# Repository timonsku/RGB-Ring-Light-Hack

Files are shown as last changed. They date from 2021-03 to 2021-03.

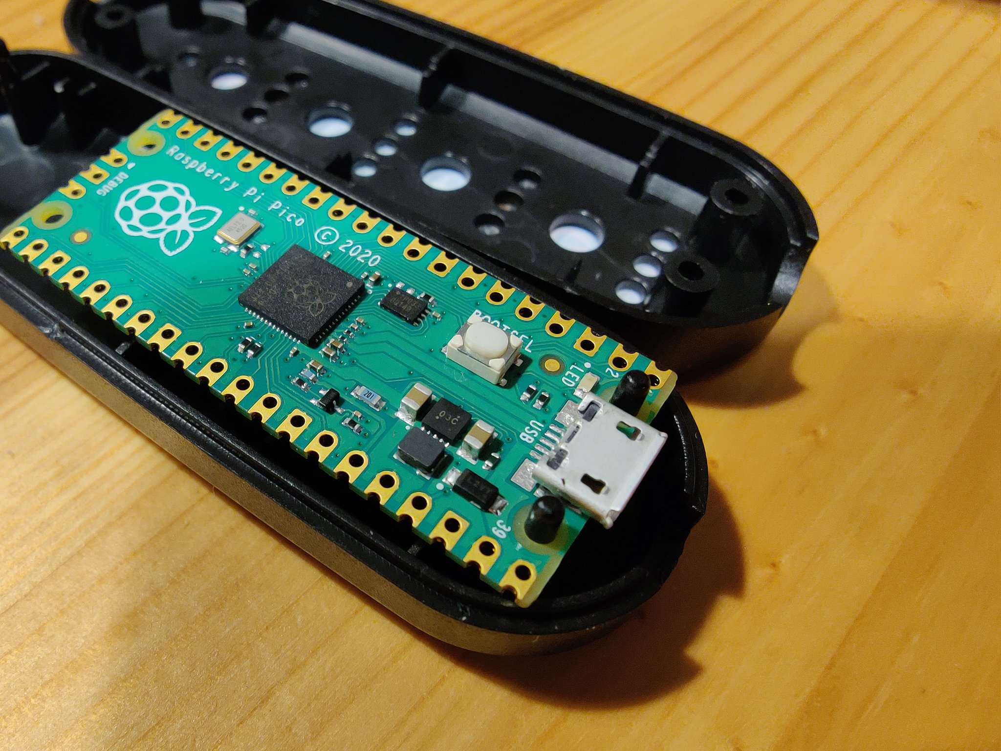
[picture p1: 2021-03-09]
Photos/pico-test-fit.jpg

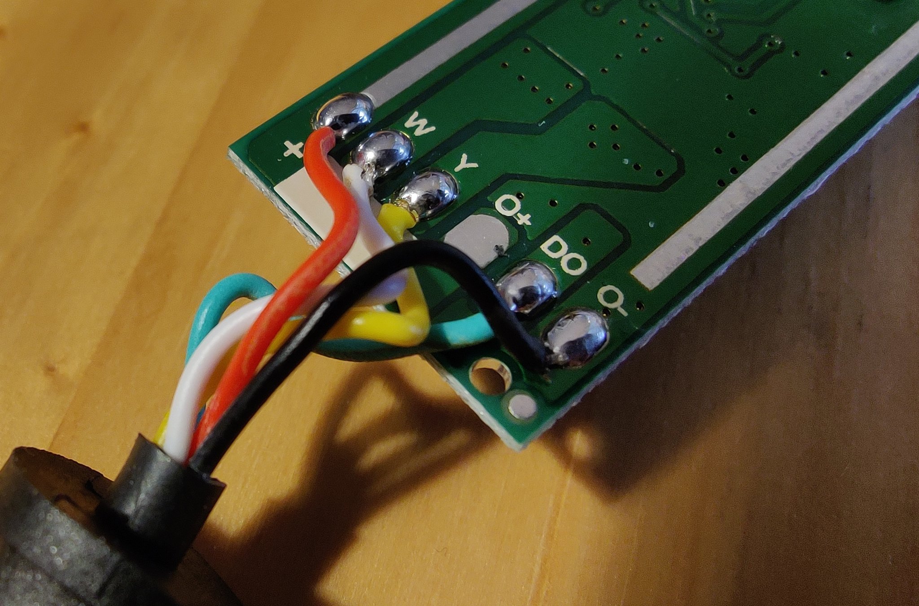
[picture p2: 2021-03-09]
Photos/pinout-original-controller.jpg

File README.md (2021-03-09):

# RGB-Ring-Light-Hack
Info and material to hack common RGB(W) ring lights with your own controller

The hack adds a Raspberry Pi Pico into the original case of the controller with some side cutter modifications and a backpack PCB that adds buttons and mosfets to control the cold and warm white LEDs.

This is based on a RGB ring light that you can buy from AliExpress, Ebay, Amazon etc.
The generic term is "10 Inch RGB Ring Light" or "10 Inch RGB Beauty Light"
The case hack that you can find in this repo is based on the model found from this vendor (affiliate link): https://s.click.aliexpress.com/e/_99rVuu

This is a high quality model of this ring light and I recommend getting that version. You might find cheaper models but they often use a different controller with a smaller case and generally a bit worse built quality, the PCB for the light seems to be generally the same though.

Demo Video

For reproducing you will need a Raspberry Pi Pico, order the PCB in `Case-Hack-PCB` and modify the case with a pair of flat side cutters according to the reference photos in `Case-Modification-Reference`. Beware of the cutouts for the buttons, you need to make them large enough so that the new buttons can fit, otherwise the case will not close well.

To open the case the first time, insert something flat/sharp between the edges of the two halfs and lever them apart, you may need to do that in multiple points before it comes apart. There is no snap fits, its just a pressure fit.

When soldering the PCB, take a look at `Case-Hack-PCB/solder-reference-headers.jpg` you need to trim the headers after soldering and add a header pointing in the opposite direction to the SWD pins for stabilization, those should be soldered first, otherwise its going to be difficult with the button pcb already in place.

I don't have the time to document this in a step by step manner. If anyone reproduces this and would like to do that, PR's are more than welcome.

Original Twitter thread with possibly some more details: https://twitter.com/timonsku/status/1357681117395103746

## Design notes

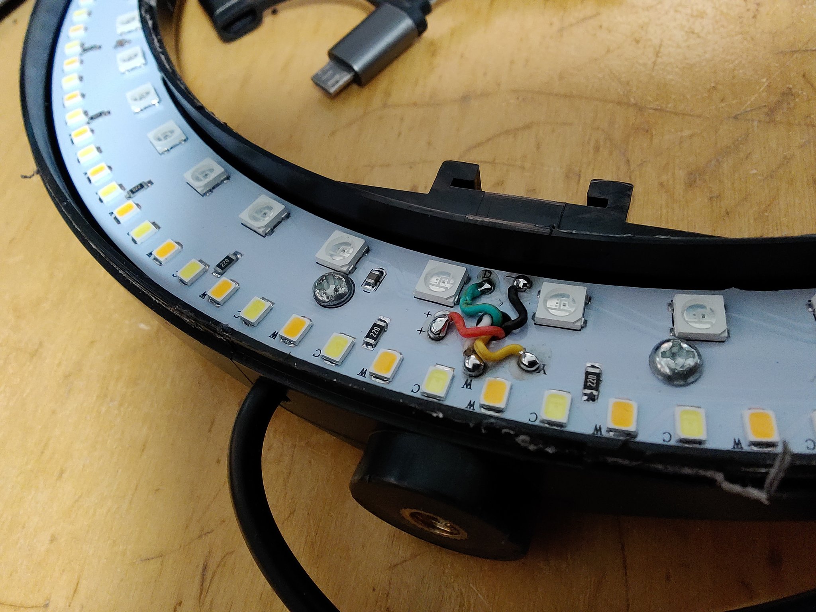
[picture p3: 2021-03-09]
Photos/inside-2.jpg

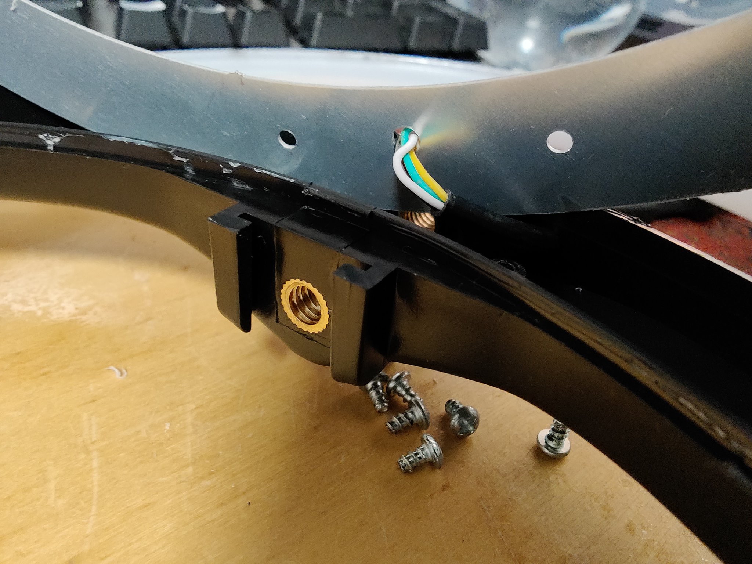
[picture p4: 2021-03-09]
Photos/inside-1.jpg

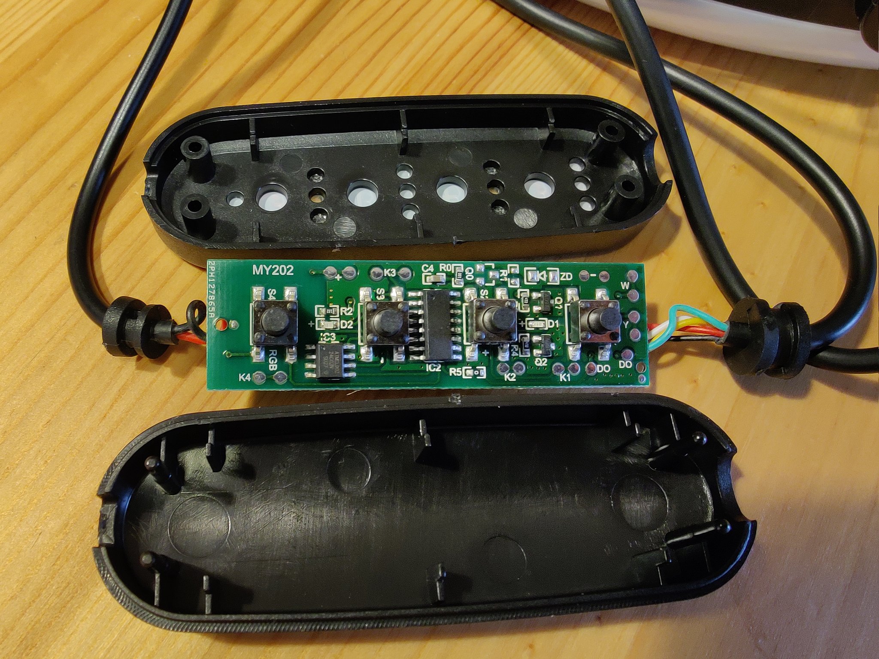
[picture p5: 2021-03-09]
Photos/original-controller.jpg

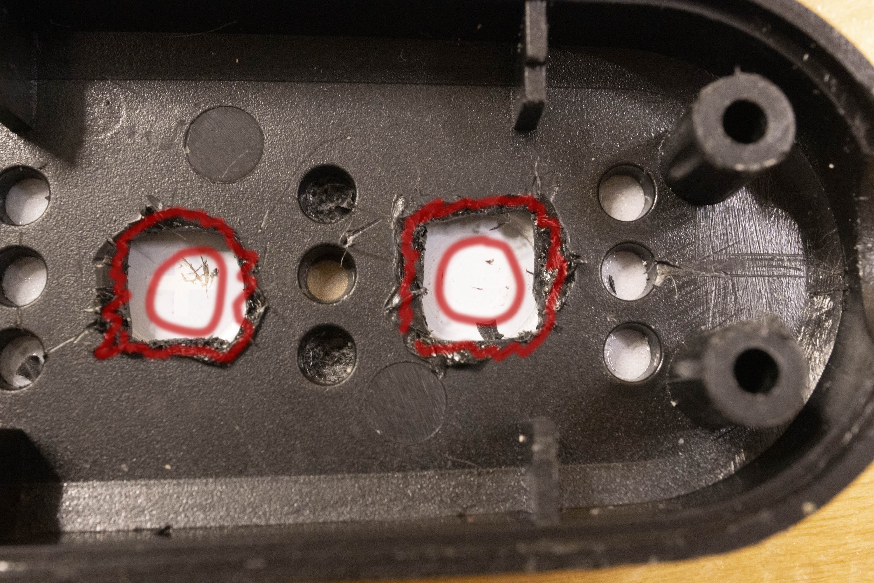
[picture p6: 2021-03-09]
Case-Modification-Reference/top-1.jpg

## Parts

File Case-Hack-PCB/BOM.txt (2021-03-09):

Buttons: K2-1109SP-B4SA-01 https://lcsc.com/product-detail/Tactile-Switches_Korean-Hroparts-Elec-K2-1109SP-B4SA-01_C92571.html

Mosfet: DMG3406L https://lcsc.com/product-detail/MOSFET_Diodes-Incorporated-DMG3406L-13_C481695.html

Generic 2.54mm Pin headers

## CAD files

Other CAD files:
Case-Hack-PCB/3D-CAD/Case-Top v10.f3z
Case-Hack-PCB/Case-Hack-PCB.f3z

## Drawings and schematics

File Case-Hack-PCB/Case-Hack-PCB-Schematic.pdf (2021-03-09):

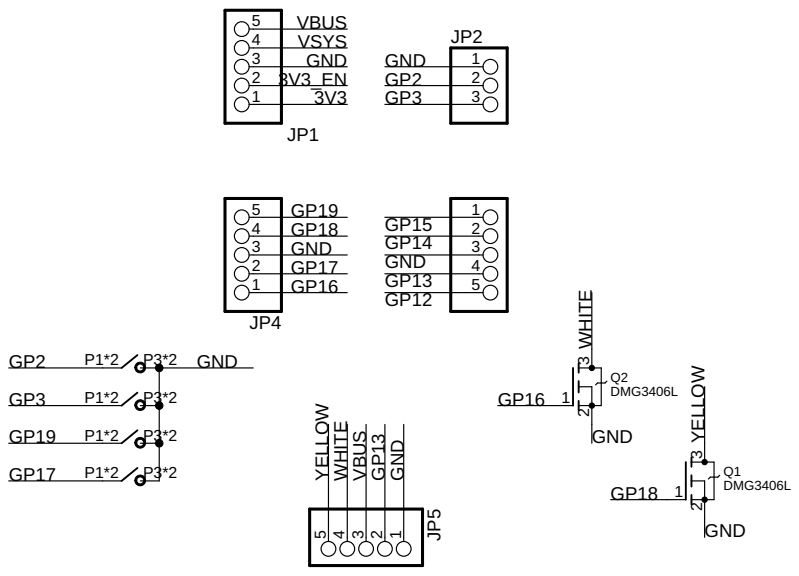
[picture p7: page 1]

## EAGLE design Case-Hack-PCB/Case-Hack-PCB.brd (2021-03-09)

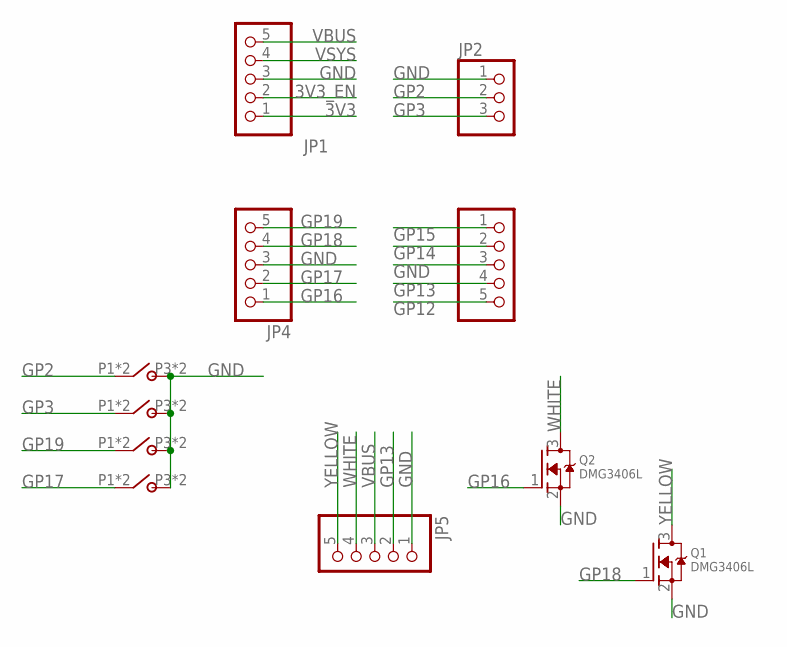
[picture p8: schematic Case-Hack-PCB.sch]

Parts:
JP1, JP3, JP4, JP5: HEADER-1X5ROUND; 1X05_ROUND
JP2: HEADER-1X3ROUND; 1X03_ROUND
Q1, Q2: DMG3406L; SOT23-WIDE
U$1, U$2, U$3, U$4: K2-1109SP-B4SA-01

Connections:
3V3: JP1.1
3V3_EN: JP1.2
GND: JP1.3, JP2.1, JP3.3, JP4.3, JP5.1, Q1.2 (S), Q2.2 (S), U$1.P3, U$1.P4, U$2.P3, U$2.P4, U$3.P3, U$3.P4, U$4.P3, U$4.P4
GP2: JP2.2, U$1.P1, U$1.P2
GP3: JP2.3, U$2.P1, U$2.P2
GP12: JP3.5
GP13: JP3.4, JP5.2
GP14: JP3.2
GP15: JP3.1
GP16: JP4.1, Q2.1 (G)
GP17: JP4.2, U$4.P1, U$4.P2
GP18: JP4.4, Q1.1 (G)
GP19: JP4.5, U$3.P1, U$3.P2
VBUS: JP1.5, JP5.3
VSYS: JP1.4
WHITE: JP5.4, Q2.3 (D)
YELLOW: JP5.5, Q1.3 (D)

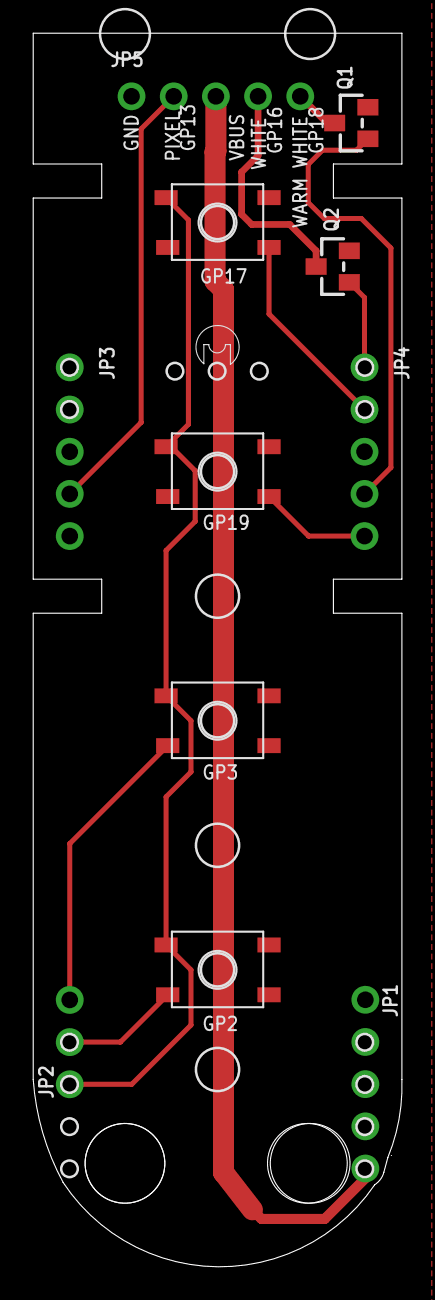
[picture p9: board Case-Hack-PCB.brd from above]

Board: 2 copper layers, 22.2 x 74.3 mm, 11 parts (0 on the bottom side), 11 nets.

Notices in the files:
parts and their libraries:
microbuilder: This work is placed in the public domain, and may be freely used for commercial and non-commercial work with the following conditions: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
